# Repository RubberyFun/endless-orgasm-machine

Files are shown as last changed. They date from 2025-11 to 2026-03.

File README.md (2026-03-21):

# Endless Orgasm Machine
**An automated orgasm denial and enhancement device for the DIY community**

### It knows...
What will surprise you most is how accurate it is that you only have a few moments left.  In this day and age algorithms are a respected part of our lives...this one knows you better than yourself.

Have you ever cut-off a sneeze before it happened and found it a conflicting blend of sensations?  Have you ever stopped before your orgasm so you could last a bit longer?  If you're not afraid to use a buttplug and you're ready for an amazing experience this is for you.  

It is not a sex-toy in the traditional sense because it doesn't provide pleasure unless you connect it to other toys.  It is an arousal sensor.  Other devices provide the pleasure, EOM tells them when to stop and when they can start again. (The exception being if you build in an integrated vibrator or e-stim plug)

### The science!
Using an inflatable butt plug to detect pressure changes indicative of pelvic floor contractions, this software, and associated hardware, is used to detect when the user is approaching orgasm and control stimulation accordingly. The net result: automated edging and orgasm denial or enhancement.

### But I like orgasms...

Having to wait for it while being right at the edge makes it more intense!  Trying to resist getting close is a turn-on for some.  When you're ready to end the edging you can use "Control: Orgasm" to allow you to finish after a chosen number of minutes or near-orgasms... if you've had enough simply set it to "Control: Manual" and take control of the toys manually.  It can also be used after orgasms to determine exactly when the refractory period has subsided enough to begin the next round of pleasuring. 

### Bonus feature:
You could use the app by itself to control multiple sex toys at once without am EOM being involved.  The app by itself is a versatile and simple control hub.

## Web UI

[The UI is posted at https://rubberyfun.github.io/endless-orgasm-machine/eomui/public](https://rubberyfun.github.io/endless-orgasm-machine/eomui/public) and can be installed on your Android or PC as a PWA app for offline use. 

This is what the app view looks like:
(the purple icon switches between chart mode and realtime mode)


For legacy purposes the UI is also on the ESP32 itself and can be found by visiting the ```/ui``` endpoint at the IP address of your device.  You can watch the serial output to determine the IP.  Due to space limitations the embedded version can't connect to other toys.  It's basically for monitoring the websocket output.

Example: If you join the EOM WiFi access point the IP will be: ```192.168.4.1``` you should visit ```http://192.168.4.1/ui```  It will automatically open a connection to the websocket endpoint at ```http://192.168.4.1/```.

 

### So how do I get one
Well, I'll get a store together eventually but for now you'll have to build it yourself.  These instructions are meant to make the simplest build possible so you can get playing. 

## Hardware
#### [Build examples here](doc/building/building.md)
STLs for the wrapped tubing version are in the [/hardware](/tree/main/hardware) directory.  

Also included are the source files for customizing your own plug.  They are designed in [OpenSCAD](https://openscad.org/), which may not be the easiest cad program to work with but its completely open-source and easily sharable for customization.

If you go with an inflatable plug you're on your own...There are not yet any files for enclosing the electronics and securing them...there are a million different products you could buy anyways so nothing could be made to fit.  If there is demand I'll post a simple box.

## Building the software
- Install [VSCode](https://code.visualstudio.com/) with the [pioarduino extension](https://github.com/pioarduino/platform-espressif32) (or add https://github.com/pioarduino/platform-espressif32 to the [PlatformIO](https://platformio.org/) extension)
- Open this repo and let all the PlatformIO dependencies download
- If you want to use websockets alongside or instead of bluetooth set "wifi_on" to true and configure your wifi ssid and password at the top of [data/config.json](data/config.json) or skip this step to let it broadcast its own access point: ```EOM```.  You can have it both ways: Set it up to connect to your home wifi but if you're away EOM will go into access point mode after it fails to find it.
- figure out the board you're using.  For a Xiao Seeed Esp32-S3 choose '''esp32-s3-devkitm-1'''.  For Waveshare Esp32-S3 choose ```waveshare_esp32_s3_zero```.  For a generic ESP32 like Wroom choose ```esp32dev```
- Under ```PlatformIO -> Project Tasks -> <your board> -> Platform``` choose ```Build Filesystem Image``` then ```Upload Filesystem Image```
- Under ```PlatformIO -> Project Tasks -> <your board> -> General``` choose ```Build``` then eventually ```Upload and Monitor```
- Watch for your device's IP address to be displayed in the monitor window 
(In access point mode it is 192.168.4.1)



## bluetooth usage
WiFi is NOT necessary anymore!  The UI can work through bluetooth now! No ip address, wifi setup, or anything else needed.  Just connect to your EOM directly by clicking the bluetooth icon.  Android or PC Chrome only! Sorry Apple and Firefox enthusiasts but those two have deemed web bluetooth an unacceptable risk and it will never be available.

So how do you get that running? It is now configured as a PWA!  This means you can pull it up once from https://rubberyfun.github.io/endless-orgasm-machine/eomui/public and install it as an app.  It does not require an internet connection to work after installation...its just there in app mode ready to go.  I'll probably end up splitting the UI into an embedded version and an app version.  

### bluetooth usage with Xtoys:
Using Xtoys you can connect to the EOM and let it control your other Xtoys devices.  For Xtoys it emulates a device called [MonsterPub Mr. Devil Kegel](https://monsterpub.com/products/mp2-u-shaped-remote-egg-with-kegel).  Connect to the device called "Libotoy".  The "pressure" reading corresponds to the "pleasure" output of the EOM.  The sliders for vibrator strength will work in manual mode.

<small>Why Mr Devil?  Because it's one of the few bluetooth devices in Xtoys that has 2 way communication and high resolution (16 bit).  If you wish to connect Xtoys to the EOM over wifi you can choose the Edge-o-matic 3000 and it is backwards compatible.  This is less useful because Xtoys only chose to implement "arousal" and "pressure" inputs, so all the logic that goes into calculating the amount of pleasure is ignored.  </small>

### Pleasure Modes:

|ID|Name|Description|
|---|---|---|
|1|Ramp-Stop|Pleasure ramps up, stopping abruptly on arousal threshold crossing.  It's very frustrating.|
|2|Depletion (default)|Pleasure ramps up, but is reduced for even small arousal spikes.  This makes for a constant interaction with your arousal rather than just a sudden cutoff when it's over the limit|
|3|Enhancement|This is the opposite of edging, it will make you orgasm faster.  Pleasure ramps up as arousal increases, holding a peak for ramp_time.  Not compatible with Orgasm mode.|

## WebSocket API

Websockets are supported for backwards compatibility with nogasm and edge-o-matic devices, but not necessary for the current bluetooth implementation.  Documentation for the WebSocket API can be found in [doc/WebSocket.md](doc/WebSocket.md).

## Building tips

You can test this out on almost any ESP32 device without any extra hardware by touching the pin assigned to the pressure sensor.  Run your finger over all the pins if you're not sure which one it is.  This will be like a pressure sensor being squeezed.  To actually play with this device you will need to attach an actual pressure sensor and butt-plug (or 3d-printed tubing version).  The [MPX5100DP](https://www.digikey.com/en/products/detail/nxp-usa-inc/MPX5100DP/464060) is the sensor it was designed around but anything capable of 15psi or greater should work whether analog or SPI.  Plug the port of the pressure sensor into the air hose for the butt plug.  

To get it to resemble [the original Nogasm device](https://github.com/nogasm/nogasm) you can then add a [12v power supply](https://www.amazon.com/ACEIRMC-Battery-Plastic-Storage-Connect/dp/B0986RMKBJ) and [charger](https://www.amazon.com/Battery-Charger-Lithium-Display-RC123A/dp/B0CRKSFTK9), a [simple transistor](https://www.amazon.com/ALLECIN-IRF4905-Transistors-IRF4905PBF-Transistor/dp/B0CBKGJT9N) or more protected [motor controller](https://www.amazon.com/High-Power-Adjustment-Electronic-Controller-Brightness/dp/B0DZP1NCVW), a [flyback diode](https://www.amazon.com/15SQ045-Diodes-Schottky-Blocking-Silicon/dp/B0D4F2WVS5), and [vibrator motor](https://www.amazon.com/RPTCOTU-R555-Vibration-Motor-Electrodynamic/dp/B0CSYWK5KQ).  You could share that power supply to the esp32 [through a buck converter](https://www.amazon.com/Regulator-Reducer-Converter-Aircraft-MP1584EN/dp/B0B779ZYN1) to make the whole thing wireless.  That's it.  You can set this all up to attach to the buttplug rather than having a wires and tubes leading to a control box, but its a matter of opinion which way is better.  

Tested boards: ESP32DEV, ESP32-WROOM32, ESP32-C6 (WaveShare), ESP32-S3 (Seeed and Waveshare)

### Customization suggestions 
- You can use [Xtoys.app](https://xtoys.app) as a control panel to ramp up any number of vibrators, strokers, or e-stim units in sync with the EOM over bluetooth.  See [this Xtoys layout for an example](https://xtoys.app/layouts/-OcwSDDWBei-Bg4xwe5o)
- If you want to connect Xtoys via wifi you will need to enable SSL in ```data/config.json``` and use the edge-o-matic Xtoys device.  The bluetooth connection is more useful since it sends pleasure level rather than arousal but there are some existing xtoys scripts that work with the edge-o-matic arousal level.
- You can use an inexpensive [Vibrating inflatable buttplug](https://www.amazon.com/Lovehoney-Black-Inflatable-Vibrating-Back/dp/B092VVXM63) and remove its control box to wire it directly to the EOM with a power circuit.  A [non-vibrating plug](https://www.amazon.com/Inflatable-Expandable-Stimulator-Beginners-Detachable/dp/B0DSPKVPM1) is even less expensive if you'll be controlling your pleasure wirelessly.
- If an [MPXV5100GP](https://octopart.com/search?q=MPXV5100GP&currency=USD) pressure sensor is too inconvenient or expensive to source you could use an easy to find [generic car exhaust pressure sensor](https://www.amazon.com/dp/B0997VKYQ9) since they are almost all analog 15psi 5v sensors.  The pin with the notch is Vin, middle is ground, third is Vout. Everything tested was 3V compatible.
- If you use an ESP32 board with an integrated screen ([Example 1](https://www.amazon.com/ideaspark-Development-Integrated-Wireless-Micropython), [Example 2](https://www.amazon.com/Waveshare-Development-Frequency-Single-Core-Processor/dp/B0DHTMYTCY)) you can enable the screen in [include/config.h](include/config.h) to see the IP of the device.
- As an alternative to a vibrating buttplug you can use [a plug made for enema play](https://www.amazon.com/Inflatable-Congestion-Cleaning-Expansion-Beginner/dp/B0CZRLPLQC) and pass a wire through the middle to an e-stim electrode or [to a vibrator on top](https://www.amazon.com/dp/B0024XI1LG).
- Someone posted a build that used tubing wrapped around a 3d printed shaft that also housed the electronics.  It was a neat new twist to the inflatable plug since the tubing reacted to pressure just like an inflatable.  The link is lost to time but it was on github somewhere.
- You could put in a higher range pressure sensor if you prefer to inflate the plug to more intense levels.  The measurement is of change in pressure, not overall pressure.
- You could order a [prebuilt PCB like is used for the Nogasm-esp32](https://github.com/Mathew3000/nogasm-esp32) 
- There really are a ridiculous number of implementations of the nogasm concept from the last decade...you should do some nogasm googling.

## Wait, isn't this the Edge-o-Matic 3000?  Or the Nogasm?

This is a fork of that project with a different set of goals.  The main goal is to make the project accessible to the maker community by keeping the hardware and software simple and DIY friendly - like [the original Nogasm](https://github.com/nogasm/nogasm) that started it all was.  The Edge-o-Matic code is designed around selling well-made but proprietary hardware and is [locked into it through closed-source code](https://github.com/MausTec/eom-hal-dist), crippling attempts to use it with DIY hardware.  It also included a lot of code to connect to related products and services.

This project was first vastly simplified then expanded with compatibility in mind.  You can try it using almost any modern ESP32 device with no additional customization.  You will need to connect a pressure sensor and inflatable buttplug to make it functional, but that's it.  It's meant to be operated wirelessly rather than through the additional hardware of a screen, knob, LEDs, network jack, etc.

Some notable differences are:
- Runs on nearly any ESP32 board!  DIY friendly
- Connects through bluetooth low energy
- Orgasm mode available over UI! (denies orgasms until timer runs out)
- Maximum denial count, so you get to finish after X number of edges
- UI hosted as PWA or on device... and is phone friendly
- defaults to endless orgasm denial in ramp-stop mode
- smaller build size, fits in your butt
- SD card requirement removed
- menu system removed
- console system removed
- action manager system removed
- hardwire networked device support removed 
- edge times are in seconds

## Standing on the shoulders of giants
This is a product of the open source community.  This will always be open source.  Sharing knowledge this way goes back to patent offices, or perhaps cave-man fire.  Sometimes the term can be abused by making things appear open when key information is obfuscated or by taking formerly open repositories offline...that practice of monetizing is also as old as time.  No shame.  Open-source doesn't mean no profiting and I'll try to make some money too. However this particular project intends to focus on information sharing and DIY accessibility as much as functionality.  You should be always be able to build this yourself if you have the free time.  That may not be the most profitable route but I hope the open-source community can elevate this project and make it even more useful than I am capable of.

## Contribution and Inspiration from:

- **Rhobot** with the original [nogasm project](https://github.com/nogasm/nogasm) that started it all
- **TheElims** Gave feedback and works on [a similar device with much more slick hardware](https://github.com/skier233/SmartAssPlug-development) - 
- **Skier23** who curates a [repository](https://github.com/Edging-Machines/Edging-Machines) and [discord](https://discord.gg/EvYbZBf) with all information regarding the topic.
- [Buttplug.io by Qdot](https://buttplug.io/) - Powers the connections from the EOM app to other bluetooth toys.  Him and his discord team are very helpful if irritable.
- **Rudolf**, who came up with the [coiled silicone tube](https://www.thingiverse.com/thing:3543727) as sensor element and even has written a [scientific paper](https://www.degruyter.com/document/doi/10.1515/pjbr-2020-0014/pdf) on that topic.
- **Maus-Tec** who manufactures and sells the [Edge-O-Matic](https://github.com/MausTec/edge-o-matic-3000)
- **Onwrikbaar** with his bullfrog, who refined the simple [nogasm algorithm](https://github.com/Onwrikbaar/Bullfrog) with a peak summation and decay function.
- **night-howler** who contributed a breadboard friendly version of the nogasm called [protogasm](https://github.com/night-howler/protogasm).

### To-do priority
- connect to DG Labs Coyote
- support for more bluetooth LED types
- add build walkthrough to docs and more examples, pinouts and schematics
- audio buzzer in ui for cooldown!
- add a config save button so setting changes aren't immediately permanent (save toy settings also/separately?)
- do canvas drawing to offscreen element for efficiency
- integrate smoothing filters into pressure readings
<!-- - ui and websockets using same endpoint if possible -->
- bug: arousal overflows on hardware side
- logging from the app
- battery monitoring characteristic
- add X axis on chart (seconds)
- chart glitch on left side at startup
- make motor pin selection more intuitive (add motor hardware in general)
- display individual toy battery levels
- bluetooth OTA?
- device disconnection (buttplug bug)
- disable internal motor control option?
- integrated screen support / ip display
- Implement patterns?  That's a biggie
- Running average math seems off

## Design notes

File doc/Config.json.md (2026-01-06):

## Configuration

Please see `data/config.json` file.
If a configuration is changed using the UI it will be saved on the device itself.  There is not currently a way to get the device's config.json back to a computer but most of its contents are transmitted via websocket when the UI first connects.  This is logged by the UI in the browser console.  The file at [/data/config.json](/data/config.json) will overwrite any changes previously saved on the ESP32 when ```PlatformIO -> Project Tasks -> esp32dev -> Platform -> Upload Filesystem Image``` is run.

Here is a quick summary of config variables:

|Key|Type|Default|Note|
|---|----|---|---|
|`wifi_ssid`|String|""|Your WiFi SSID.|
|`wifi_key`|String|""|Your WiFi Password.|
|`wifi_on`|Boolean|false|Enable WiFi and the Websocket server. Cannot be enabled if AzureFang is on.|
|`bt_display_name`|String|"Libotoy"|BT device name.  Currently emulates MonsterPub device for Xtoys compatibility.|
|`bt_on`|Boolean|true|Enable BT connectivity.|
|`force_bt_coex`|Boolean|false|Force BT and WiFi at the same time.|
|`led_brightness`|Byte|128|Status LED maximum brightness.|
|`websocket_port`|Int|80|Port to listen for incoming Websocket connections.|
|`use_ssl`|Boolean|true|Enable SSL server, which is a bit annoying to accept unsigned certificates but required for xtoys compatibility|
|`hostname`|String|"eom3k"|Local hostname for your device.|
|`chart_window_s`|Int|5|The number of seconds to display in the chart history.  Higher numbers can cause sluggish behavior on slower devices|
|`max_denied`|Int|20|Maximum number of denials before forcing an orgasm (in orgasm mode).|
|`initial_pleasure`|Byte|10|The minimum speed the motor will start at in endless & orgasm mode.|
|`max_pleasure`|Byte|255|Maximum speed for the motor in auto-ramp mode.|
|`motor_ramp_time_s`|Int|30|The time it takes for the motor to reach Motor Max Speed in endless & orgasm mode.|
|`edge_delay`|Int|10|Minimum time (s) after edge detection before resuming stimulation.|
|`max_additional_delay`|Int|10|Maximum time (s) that can be added to the edge delay before resuming stimulation. A random number will be picked between 0 and this setting each cycle. 0 to disable.|
|`minimum_on_time`|Int|1|Time (s) after stimulation starts before edge detection is resumed.|
|`pressure_smoothing`|Byte|5|Number of samples to take an average of. Higher results in lag and lower resolution!|
|`classic_serial`|Boolean|false|Output continuous stream of arousal data over serial for backwards compatibility with other software.|
|`sensitivity_threshold`|12 bit Int (4096)|1024|The arousal threshold for orgasm detection. Lower values stop sooner.|
|`mid_threshold`|12 bit Int (4096)|512| The start of the warning zone for approaching arousal.  Changes lights to yellow.|
|`update_frequency_hz`|Int|50|Update frequency for pressure readings and arousal steps. Higher = crash your serial monitor.|
|`sensor_sensitivity`|Byte|128|Pressure sensor prescaling.|
|`use_average_values`|Boolean|false|Use average values when calculating arousal. This smooths noisy data.|
|`vibration_mode`|VibrationMode|RampStop|Vibration Mode for main vibrator control.|
|`use_post_orgasm`|Boolean|false|Use post-orgasm torture mode and functionality.|
|`clench_pressure_sensitivity`|Int|200|Minimum additional Arousal level to detect clench. See manual.|
|`clench_time_to_orgasm_ms`|Int|1500|Threshold variable that is milliseconds count of clench to detect orgasm. See manual.|
|`clench_detector_in_edging`|Boolean|false|Use the clench detector to adjust Arousal. See manual.|
|`auto_edging_duration_minutes`|Int|30|How long to edge before permiting an orgasm.|
|`post_orgasm_duration_seconds`|Int|10|How long to stimulate after orgasm detected.|
|`edge_menu_lock`|Boolean|false|Deny access to menu starting in the edging session.|
|`post_orgasm_menu_lock`|Boolean|false|Deny access to menu starting after orgasm detected.|
|`max_clench_duration_ms`|Int|3000|Duration the clench detector can raise arousal if clench detector turned on in edging session.|
|`clench_time_threshold_ms`|Int|900|Threshold variable that is milliseconds counts to detect the start of clench.|

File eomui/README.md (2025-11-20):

# Endless Orgasm Machine UI

This is a browser-based UI for the Endless Orgasm Machine system for ESP32.



It runs over bluetooth!  Just connect to your EOM directly by clicking the bluetooth icon.  No ip address, wifi setup, or websockets needed.  For now it is Android or PC Chrome or Edge only! Sorry Apple and Firefox enthusiasts but they have deemed web bluetooth an unacceptable risk and it will never be available.  I'm working on a native wrapper to get past this and into the app stores.

It is configured as a PWA!  This means you can pull it up once from https://rubberyfun.github.io/endless-orgasm-machine/eomui/public and install it as an app.  It does not require an internet connection to work after installation...its just there in app-mode ready to go.

It was meant to be stored in spiffs memory on an ESP32 but has outgrown that with the addition of buttplug.io connections to other sex toys.  A simpler version of the built output is included with the larger EOM project for monitoring websocket output. 

It can be run locally if you prefer.  It should be backwards compatible with the Edge-o-Matic & nogasm though missing some features like denial count and Orgasm Mode.


## Use
- Click the bluetooth icon to connect to the EOM (it should be visible as "Libotoy").  The UI will now respond to the pressure applied to the EOM
- Click the duck icon to connect to a toy such as a vibrator.  The toy will now increase in intensity along with the "pleasure" meter of the app.
- If clenches are detected by the EOM the "pleasure" meter will drop accordingly and the toy will follow.

## Building 
- from the eomui directory run ```npm install``` then ```npm run build```
- the output ```index.html``` will automatically overwrite the version in the /data directory of the EOM project.
- using platformIO tools ```build filesystem``` then ```upload filesystem``` to update your device
- the EOM code itself doesn't need to be built/uploaded again

## Development
- run ```vite```
- visit ```http://localhost:5173/``` in your browser
- enter the ip address of your EOM and hit connect - it will open a websocket connection and request a stream of readings
- to speed up development the IP address can be entered into the code on line 8 of [/src/App.svelte](/src/App.svelte) 
- if you need SSL locally use ```npm i @vitejs/plugin-basic-ssl```

## License
This UI was not derived from any previous projects and is released under GPL courtesy of Claus Macher.  If you aren't familiar with GPL it basically means you can do whatever you want with the code but anything you make with it should also be released under GPL.

The buttplug.io library used by this project has a BSD-3 License...which basically means the license and attribution must be distributed with any projects using the code.

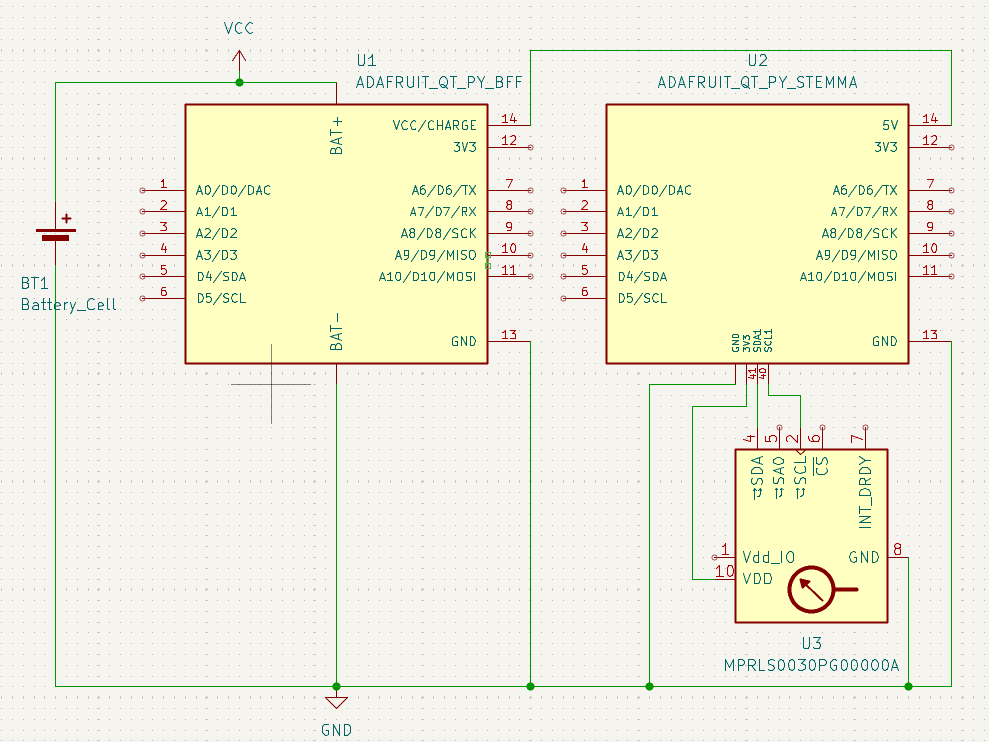
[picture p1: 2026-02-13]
doc/building/QT_PY_wBFF_I2C schematic.png

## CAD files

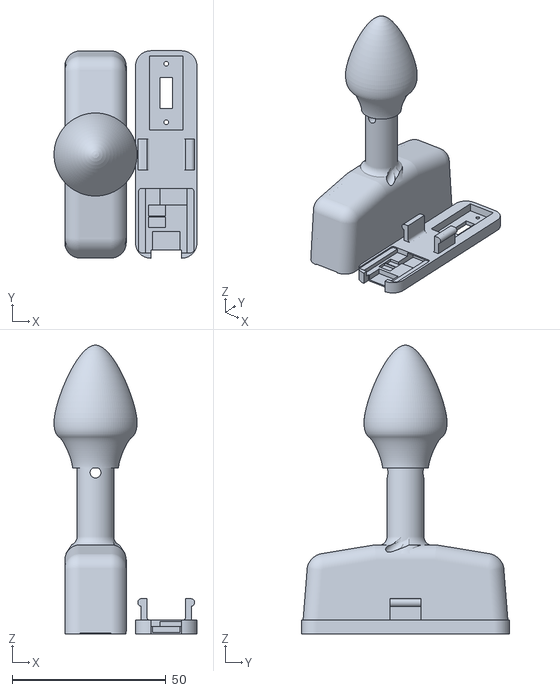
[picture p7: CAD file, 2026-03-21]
hardware/plugXS.stl
46.5 x 67.5 x 94.0

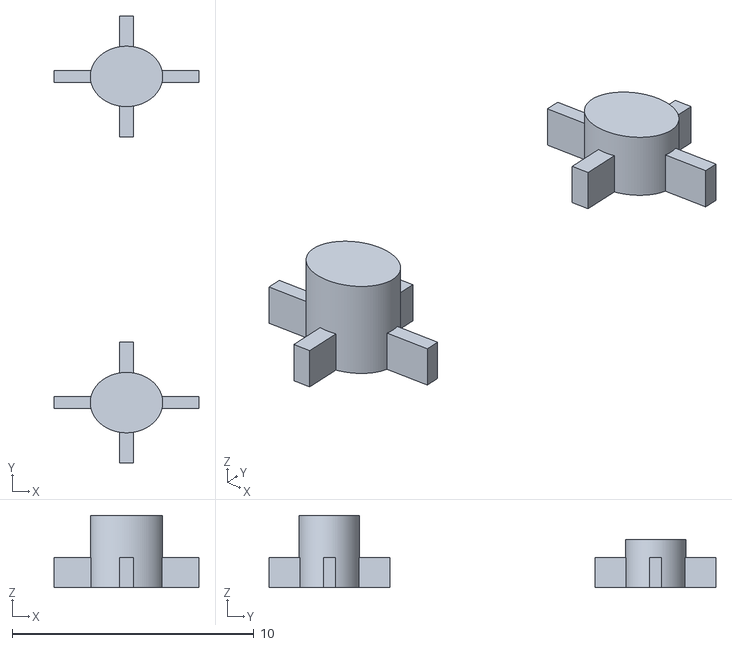
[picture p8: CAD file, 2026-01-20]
hardware/buttons.stl
6.00 x 18.5 x 3.00

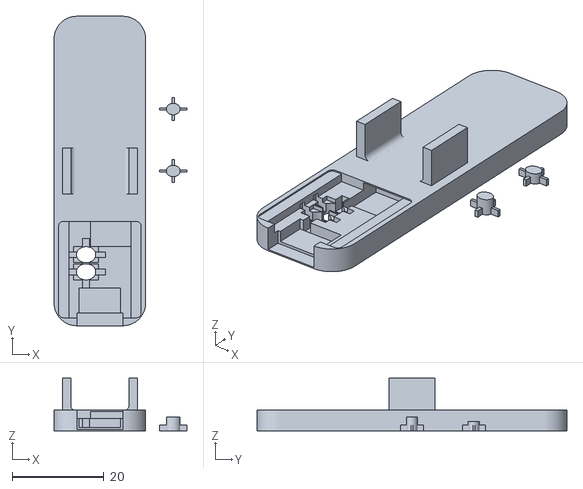
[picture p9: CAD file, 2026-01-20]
hardware/lid.stl
29.0 x 67.5 x 11.5

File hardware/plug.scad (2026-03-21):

include <BOSL2/std.scad> //You will need to install the BOSL2 library to your openSCAD library (https://github.com/BelfrySCAD/BOSL2):
$fn = 100;

show_body = true;
show_lid = true;
lid_offset = true;  //for 3d printing
show_cap = true;
preview_electronics = false; //false for printing
show_mold = false;

seed_w = 18;
seed_h = 2;
seed_l = 21;
usb_d = 9;
usb_w = 9;
usb_h = 3.5;
button_w = 4.5;
button_d = 3.5;
switch_hinge_w = 1;
seed_clearance_h = 1.5;
seed_clearance_w = 13.5;

ps_w = 8;
ps_h = 10;
ps_d = 8;

battery_w = 50;
battery_h = 20;
battery_d = 10;

box_iw = 60;
box_ih = 23;
box_id = 16;
box_top_rise = 3;
box_fillet = 5;
box_bottom_fillet_hack = 5;
box_lid_h = 5.5;
box_lid_side_clip_h = 2;
box_lid_side_clip_l = 7 + box_lid_side_clip_h;
box_lid_side_clip_w = 10;


shaft_od = 12;
shaft_h = 25;

cap_bottom_h = 10;
cap_middle_h = 5;
cap_top_h = 25;
cap_middle_od = 27;

wall_thickness = 2;
tubing_od = 3;
tubing_od_allowance = 1;

switch_screw_l = 19;
switch_screw_d = 1.5;
switch_l = 24;
switch_w = 11;
switch_h = 11;
switch_lever_l = 10;
switch_lever_w = 4;
switch_lever_h = 3;

if (show_lid && !show_mold) 
  if (lid_offset) 
    translate([box_ih, 0, + box_lid_h ]) 
      lid();
  else 
  //translate([box_id/2,0,-box_ih]) 
  lid();
if (show_body && !show_mold) body();
if (show_cap && !show_mold) cap();

box_points = [
  [-box_iw / 2 - wall_thickness * 2, -box_ih / 2 - box_fillet - wall_thickness], //bottom left
  [box_iw / 2 + wall_thickness * 2, -box_ih / 2 - box_fillet - wall_thickness], //bottom right
  //[box_iw/2 + wall_thickness,                     box_ih/2], //top right corner
  for (
    //top right side curve;
    i = bezpath_curve(
      [
        [box_iw / 2 + wall_thickness, box_ih / 2 - box_fillet],
        [box_iw / 2 + wall_thickness, box_ih / 2 - box_fillet / 2],
        [box_iw / 2 + wall_thickness - box_fillet / 2, box_ih / 2],
        [box_iw / 2 + wall_thickness - box_fillet, box_ih / 2 + (box_fillet / (box_iw / 2 + wall_thickness))],
      ]
    )
  ) i,
  [shaft_od / 2 + tubing_od + tubing_od_allowance, box_ih / 2 + box_top_rise], //shaft right
  [-shaft_od / 2 - tubing_od - tubing_od_allowance, box_ih / 2 + box_top_rise], //shaft left
  //[-box_iw/2 - wall_thickness,                    box_ih/2]  //top left corner
  for (
    //top left side curve;
    i = bezpath_curve(
      [
        [-box_iw / 2 - wall_thickness + box_fillet, box_ih / 2 + (box_fillet / (box_iw / 2 + wall_thickness))],
        [-box_iw / 2 - wall_thickness + box_fillet / 2, box_ih / 2],
        [-box_iw / 2 - wall_thickness, box_ih / 2 - box_fillet / 2],
        [-box_iw / 2 - wall_thickness, box_ih / 2 - box_fillet],
      ]
    )
  ) i,
];

bottom_of_shaft = box_ih / 2 + box_top_rise + wall_thickness;

module body() {
  //components compartment
  difference() {
    #union() {
      translate([-box_id / 2 - wall_thickness, 0, tubing_od_allowance * 2])
        rotate([90, 0, 90])
          //filleted top and bottom
          fillet_extrude(height=box_id + wall_thickness * 2, r1=-5, r2=-5)
            polygon(box_points);

      //shaft tubing collar
      difference() {
        translate([0, 0, bottom_of_shaft]) cylinder(h=shaft_od / 2 -.5, d1=box_id + wall_thickness*2 - .825, d2=shaft_od, center=true); //.825 to account for fillet overlap
        translate([0, 0, bottom_of_shaft + 2.75]) torus(id=shaft_od-.001, od=shaft_od * 2, $fn=100);
      }
    }

    //cut off bottom of box
    translate([0, 0, -box_ih / 2 - box_fillet - wall_thickness/2])
      cube([box_iw + wall_thickness * 2, box_iw + wall_thickness * 2 + box_fillet * 2, box_fillet * 2], center=true);

    //insert for esp32
    translate([0,-box_iw/2 + seed_l/2 - wall_thickness, -box_ih/2  -.2501]) qt_py_esp32s3(); //.25 because im getting overhang artifacts when it's flush
    //translate([0, box_iw/2 - seed_l/2 + wall_thickness, -box_ih / 2 +3]) qt_py_bff();

    if (!show_mold) {

      //cavity for electronics
      translate([0, 0, -wall_thickness/2])
        cube([box_id, box_iw, box_ih], center=true);

      //center hole for wire
      cylinder(h=shaft_h + 2, d=tubing_od, center=true); 

      //hole for pressure tube
      translate([shaft_od / 2 + tubing_od / 2, -shaft_od/4, bottom_of_shaft])
        rotate([-45, 0, 0])
          cylinder(h=box_ih, d=tubing_od + tubing_od_allowance / 2, center=true);

      //hole for pressure tube onto shaft
      translate([shaft_od / 2 + tubing_od / 2 + .25,0, bottom_of_shaft+tubing_od/2 + .25]) {

        //this is a failed attempt to use an arc of torus, but i still think its the right approach eventually so it stays
        // rotate([-5,0,0]) translate ([0,1,0]) intersection() {
        //   translate([0,-3,2]) rotate([20,0,0]) rotate([0,90,0]) cylinder(h=30, d=16, center=true,$fn=3);
        //   c = 10;
        //   translate([1,1,-c/1.5 ]) rotate([0,90,-2]) torus(od=c+shaft_od, id=c);     
        // }
       translate([1.1,0,.75]) rotate([110,-15,-8]) cylinder (h=8, d=shaft_od/2, center=true);  //just another cylinder for now

      //tab stays
      for (side = [0,-1]) 
        translate([side *  box_id + .25, 0, - box_ih - wall_thickness]) 
          rotate([90,0,0]) 
            cylinder(h=box_lid_side_clip_w + 4, d=box_lid_side_clip_h + .5, center=true);

      }
        // rotate([-67.5, 0, 0])
        //   cylinder(h=18, d=tubing_od + tubing_od_allowance / 2, center=true);
    }
  }

  if (!show_mold) {
    //shaft
    difference() {
      translate([0, 0, bottom_of_shaft + shaft_h / 2])
        cylinder(h=shaft_h, d=shaft_od, center=true);
      //shaft

      translate([0, 0, bottom_of_shaft + shaft_h / 2])
        cylinder(h=shaft_h + 2, d=tubing_od, center=true);
      //hole up the middle
      translate([0, 0, bottom_of_shaft + shaft_h - tubing_od / 2])
        rotate([90, 0, 0])
          cylinder(h=cap_middle_od + 2, d=tubing_od + tubing_od_allowance / 2, center=true);
      //hole for tubing end
    }
  }
}

top_of_shaft = bottom_of_shaft + shaft_h;

module cap() {
  cap_points = [
    [0, top_of_shaft], //point
    [tubing_od / 4, top_of_shaft],
    [tubing_od / 2, top_of_shaft],
    [shaft_od / 2 + tubing_od / 2, top_of_shaft], //point
    [shaft_od / 2 + tubing_od / 2, top_of_shaft + cap_bottom_h / 4],
    [cap_middle_od / 2 * .75, top_of_shaft + cap_bottom_h - cap_middle_h / 4],
    [cap_middle_od / 2 * .875, top_of_shaft + cap_bottom_h], //point
    [cap_middle_od / 2, top_of_shaft + cap_bottom_h + cap_middle_h / 4],
    [cap_middle_od / 2, top_of_shaft + cap_bottom_h + cap_middle_h * .75],
    [cap_middle_od / 2, top_of_shaft + cap_bottom_h + cap_middle_h], //point
    [cap_middle_od / 2, top_of_shaft + cap_bottom_h + cap_middle_h + cap_top_h / 4],
    [shaft_od / 2, top_of_shaft + cap_bottom_h + cap_middle_h + cap_top_h],
    [0, top_of_shaft + cap_bottom_h + cap_middle_h + cap_top_h], //point
  ];
  rotate_extrude()
    //create cap shape
    polygon(bezpath_curve(cap_points));
}

module lid() {
  //components back cover
  translate([0, 0,-box_ih / 2 - 1]) { // magic -1
    //?
    color("purple") 
      //scale([1, 1, .5])
        difference() {
            cuboid ([box_id + wall_thickness * 2, box_iw + wall_thickness * 3.75, box_lid_h * 2], rounding=box_fillet,edges="Z"); //lid box);

          //cut off top
          translate([0,0, box_lid_h/2]) 
            cube([box_iw + wall_thickness * 2, box_iw + wall_thickness * 2 + box_fillet * 2, box_lid_h +2],center=true);

          //usb cutout
          //translate([0,-box_iw/2 - usb_d + wall_thickness/2,-.5])cube([usb_w + 2, usb_d*2, usb_h + 2], center=true); //magic .5 for height clarance

          //esp32 cutout
          translate([0,-box_iw/2 + seed_l/2 - wall_thickness, -.5]) qt_py_esp32s3(); 
          // translate([0, box_iw/2 - seed_l/2 + wall_thickness, 2.25]) qt_py_bff();  //.25 of cheat
          translate([0, box_iw/2 - switch_l/2 + wall_thickness, switch_lever_h/2]) switch();

          //button press mechanism 
         // #translate([-button_w/2, -box_iw/2 + wall_thickness + button_d/2, -5])
        }

        //bff stays
        // translate([0, box_iw/2 - seed_l/2 + wall_thickness, 1.5]) {
        //   for (side = [-1, 1]) 
        //     color("green") translate([side*6,2.5,-2]) cube([2,4,2], center=true);
        // }

        //side clips
        for (side = [-1, 1]) {
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

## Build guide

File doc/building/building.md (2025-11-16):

# Building an EOM

Todo: build walkthroughs

# Example builds:

### Tiny tubing build with colored lights (~$60)
- $7 [Waveshare ESP32-S3](https://www.amazon.com/dp/B0CR2RH7PS)
- $28 [MPXV5050GP pressure sensor](https://www.digikey.com/en/products/detail/nxp-usa-inc/MPXV5100GP/2186552) + shipping + tax
- $6 [2mm ID silicone tubing](https://www.amazon.com/Rebower-Silicone-Silicon-Brewing-Aquaponics/dp/B0DSPVD4V7)
- $8 [1100ma battery with jst 1.5 connector](https://www.amazon.com/dp/B0F1FN9BY6)
- $6-$11 [USB battery charger](https://www.adafruit.com/product/6091)([amazon source](https://www.amazon.com/Treedix-Protection-Adjustable-Power-Down-Regulation/dp/B09FJJBLQ1) / [amazon source with data passthrough](https://www.amazon.com/Adafruit-4410-Micro-Charger-LiPoly/dp/B08168GWVJ))
- [3d printed base](../../hardware/plugXS.stl)
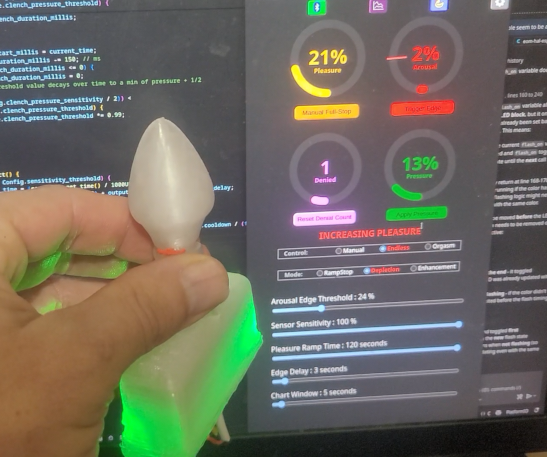
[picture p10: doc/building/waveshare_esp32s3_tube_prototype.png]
Waveshare ESP32-S3 tubing build

---
### Custom PCB (~$150): [Mathew3000/nogasm-esp32](https://github.com/Mathew3000/nogasm-esp32) 
PCB can be ordered online using the files in the repo.  About $150
Mathew3000/nogasm-esp32 

---
### Tiny tubing build with integrated battery (~$60)
- \$8 [Xiao Seeed ESP32-S3](https://www.digikey.com/en/products/detail/seeed-technology-co-ltd/113991114/19285530)  ([$17 on amazon](https://www.amazon.com/ESP32S3-2-4GHz-Dual-core-Supported-Efficiency-Interface/dp/B0BYSB66S5))
- $28 [MPXV5100GP pressure sensor](https://www.digikey.com/en/products/detail/nxp-usa-inc/MPXV5100GP/2186552) \$20 + shipping + tax
- $6 [2mm ID silicone tubing](https://www.amazon.com/Rebower-Silicone-Silicon-Brewing-Aquaponics/dp/B0DSPVD4V7)
- $5 [jst 1.5 connectors](https://www.amazon.com/dp/B07FP2FCYC) 
- $8 [1100ma 102540 battery with jst 1.5 connector](https://www.amazon.com/dp/B0F1FN9BY6)
- [3d printed base](../../hardware/plugXS.stl)

### Small 18650 inflatable build
- $7 [Waveshare ESP32-S3](https://www.amazon.com/dp/B0CR2RH7PS)
- $20 [MPXV5100GP pressure sensor](https://www.digikey.com/en/products/detail/nxp-usa-inc/MPXV5100GP/2186552)
- $15 [inflatable butt plug](https://www.amazon.com/Inflatable-Expandable-Stimulator-Beginners-Detachable/dp/B0DSPKVPM1)
- $20 [battery, charger, and connectors](https://www.amazon.com/dp/B08XZM3NG3)

### Small DIY with all the features (WIP)
- $20 [ESP32-C6 with integrated screen](https://www.amazon.com/dp/B0DHTMYTCY)
- $25 [MPX5100GP pressure sensor](https://www.digikey.com/en/products/detail/nxp-usa-inc/MPX5100GP/464061) (or use the smaller MPXV5100GP if you like)
- $20 [Enema inflatable buttplug](https://www.amazon.com/Inflatable-Congestion-Cleaning-Expansion-Beginner/dp/B0CZRLPLQC)
- An egg electrode (this will connect to your e-stim unit after passing through the plug, not the EOM)
- A small vibrator to fit inside the enema plug
- A transistor to control the vibe with
- A flyback diode to protect the circuit from the motor
- $20 [battery, charger, and connectors](https://www.amazon.com/dp/B08XZM3NG3)
- 3D printed case

### Cheapest possible (~$40 and its usable, but more likely just for testing):
- $15 [inflatable butt plug](https://www.amazon.com/Inflatable-Expandable-Stimulator-Beginners-Detachable/dp/B0DSPKVPM1)
- $12 [generic car exhaust pressure sensor](https://www.amazon.com/dp/B0997VKYQ9)
- $5 [ESP32](https://www.amazon.com/dp/B0F1MS5S8R)
- $7 [18650 cell](https://www.amazon.com/CWUU-9900mAh-Rechargeable-Flashlights-Headlamps/dp/B0D12P7L29)
- $1 [battery holder](https://www.amazon.com/DIANN-10pcs-Battery-Holder-Single/dp/B0BJV7SK5D)
- hot glue and rubber bands, or just use the full length of the tube and let it rest somewhere

Cheapo Build

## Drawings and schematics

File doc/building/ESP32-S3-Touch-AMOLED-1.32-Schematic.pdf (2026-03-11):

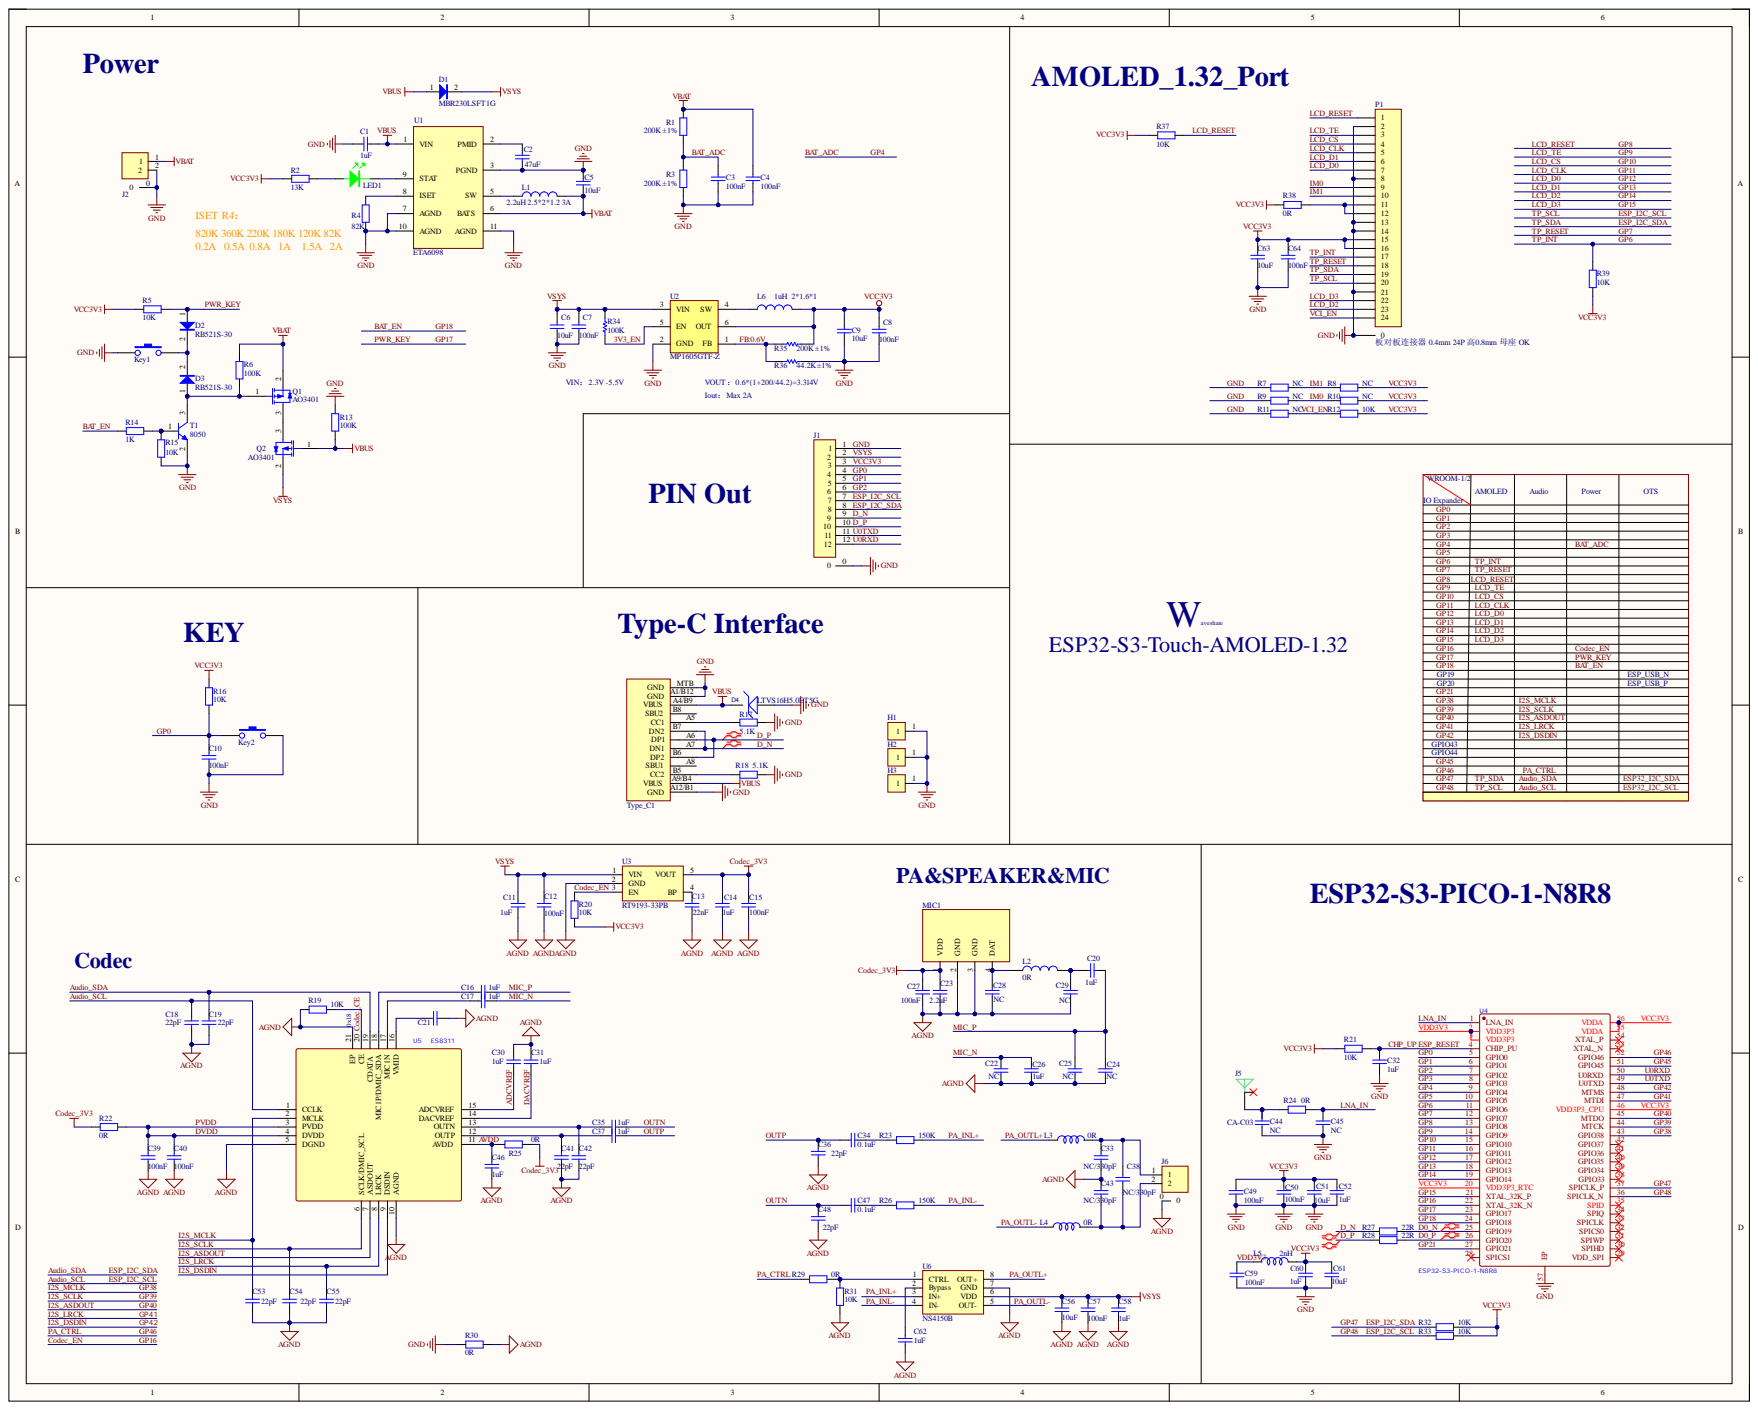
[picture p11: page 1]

GP5
GP6 | TP_INT
GP7 | TP_RESET
GP8 | LCD_RESET
GP9 | LCD_TE
GP10 | LCD_CS
GP11 | LCD_CLK
GP12 | LCD_D0
GP13 | LCD_D1
GP14 | LCD_D2
GP15 | LCD_D3
GP16 | | Codec_EN
GP17 | | PWR_KEY
GP18 | | BAT_EN
GP19 | | | ESP_USB_N

GP47 | TP_SDA | Audio_SDA | ESP32_I2C_SDA
GP48 | TP_SCL | Audio_SCL | ESP32_I2C_SCL

VMID 16 MIC1N 17 MIC1P/DMIC_SDA 18 CDATA 19 CE 20 EP 21

I2S_ASDOUT
I2S_LRCK

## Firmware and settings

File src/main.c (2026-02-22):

#include "api/broadcast.h"
#include "config.h"
#include "config_defs.h"
#include "eom-hal-esp32.h"
#include "freertos/FreeRTOS.h"
#include "freertos/task.h"
#include "gatt_svc.h"
#include "orgasm_control.h"
#include "polyfill.h"
#include "system/http_server.h"
#include "version.h"
#include "wifi_manager.h"
#include <esp_https_ota.h>
#include <esp_ota_ops.h>
#include <esp_system.h>
#include <esp_sleep.h>
#include <driver/gpio.h>
#include "driver/rtc_io.h"
#include <time.h>
#include <nvs_flash.h>
#include <esp_spiffs.h>


char* TAG = "main";


void spiffs_init() {
        ESP_LOGI(TAG, "Initializing SPIFFS");

    esp_vfs_spiffs_conf_t conf = {
      .base_path = "/spiffs",
      .partition_label = "spiffs",
      .max_files = 5,
      .format_if_mount_failed = true
    };

    esp_err_t ret = esp_vfs_spiffs_register(&conf);

    if (ret != ESP_OK) {
        if (ret == ESP_FAIL) {
            ESP_LOGE(TAG, "Failed to mount or format filesystem");
        } else if (ret == ESP_ERR_NOT_FOUND) {
            ESP_LOGE(TAG, "Failed to find SPIFFS partition");
        } else {
            ESP_LOGE(TAG, "Failed to initialize SPIFFS (%s)", esp_err_to_name(ret));
        }
        return;
    }
    ESP_LOGI(TAG, "SPIFFS registered");
}

// static void orgasm_task(void* args) {
    // for (;;) {
    // orgasm_control_tick();

    // vTaskDelay(1);
    // }
// }

static void ble_task(void* args) {
    for (;;) {   
    send_output1();

    vTaskDelay(10);
    }
}


static void loop_task(void* args) {
    // for (;;) {
    static long lastStatusTick = 0;
    static long lastTick = 0;

    // Periodically send out WiFi status:
    if (millis() - lastStatusTick > 1000 * 10) {
        lastStatusTick = millis();
        api_broadcast_network_status();
    }

    if (millis() - lastTick > 1000 / 15) {
        ESP_LOGD(
            TAG,
            "%%heap=%d, min=%d, internal=%d",
            esp_get_free_heap_size(),
            esp_get_minimum_free_heap_size(),
            esp_get_free_internal_heap_size()
        );

        lastTick = millis();
        api_broadcast_readings();
    }

    // Tick and see if we need to save config:
    config_enqueue_save(-1);

    vTaskDelay(1);
}


static void main_task(void* args) {
    orgasm_control_set_output_mode(OC_AUTOMATIC);

    for (;;) {
        //loop_task(NULL);
        orgasm_control_tick();
        eom_hal_led_tick();

        //send_output1();
        vTaskDelay(1);
    }
}

static void sleep_monitor_task(void* args) {
    if (SLEEP_GPIO < 1) {
        ESP_LOGI(TAG, "SLEEP_GPIO not configured, sleep monitor disabled");
        vTaskDelete(NULL);
        return;
    }

    // Configure GPIO as input with pull-down
    gpio_config_t io_conf = {
        .pin_bit_mask = (1ULL << SLEEP_GPIO),
        .mode = GPIO_MODE_INPUT,
        .pull_up_en = GPIO_PULLUP_ENABLE,
        .pull_down_en = GPIO_PULLDOWN_DISABLE,
        .intr_type = GPIO_INTR_DISABLE
    };
    esp_err_t ret = gpio_config(&io_conf);
    if (ret != ESP_OK) {
        ESP_LOGE(TAG, "Failed to configure SLEEP_GPIO %d: %s", SLEEP_GPIO, esp_err_to_name(ret));
        vTaskDelete(NULL);
        return;
    }

    ESP_LOGI(TAG, "Sleep monitor initialized on GPIO %d", SLEEP_GPIO);

    TickType_t sleep_debounce_until = 0;

    for (;;) {
        int level = gpio_get_level(SLEEP_GPIO);
        ESP_LOGD(TAG, "Sleep signal on GPIO %d", level);
        
        // Ignore LOW levels during debounce period
        if (level == 0 && xTaskGetTickCount() < sleep_debounce_until) {
            ESP_LOGD(TAG, "Ignoring LOW level during debounce period");
            vTaskDelay(pdMS_TO_TICKS(100));
            continue;
        }
        
        if (level == 0) {
            ESP_LOGI(TAG, "Entering sleep...");
            
            
            // Configure wake-up source
            
            if (LED_POWER > -1) {
                gpio_set_level(LED_POWER, 0); //power off the LED
            }
            
            // Disable pullup for sleep
            // io_conf.pull_up_en = GPIO_PULLUP_DISABLE;
            // esp_err_t ret = gpio_config(&io_conf);
            if (ret != ESP_OK) {
                ESP_LOGE(TAG, "Failed to re-configure SLEEP_GPIO %d: %s", SLEEP_GPIO, esp_err_to_name(ret));
            }
            
            // Give time for log message to be sent and button to be released
            
            // Enter sleep
            // rtc_gpio_pullup_dis(SLEEP_GPIO);
            // rtc_gpio_pulldown_en(SLEEP_GPIO);
            // esp_sleep_enable_ext0_wakeup(SLEEP_GPIO, 1);
            vTaskDelay(pdMS_TO_TICKS(500));
            esp_sleep_enable_gpio_wakeup();
            gpio_wakeup_enable(SLEEP_GPIO, GPIO_INTR_LOW_LEVEL);
            esp_light_sleep_start();
            ESP_LOGI(TAG, "esp_sleep.wake_reason=%d", esp_sleep_get_wakeup_cause());
            
            // Set debounce period: ignore LOW levels for 1 second after waking
            sleep_debounce_until = xTaskGetTickCount() + pdMS_TO_TICKS(1000);
            
            // rtc_gpio_deinit(SLEEP_GPIO) ;
            // Re-enable pullup for sleep
            // io_conf.pull_up_en = GPIO_PULLUP_ENABLE;
            ret = gpio_config(&io_conf);
            if (ret != ESP_OK) {
                ESP_LOGE(TAG, "Failed to re-configure SLEEP_GPIO %d: %s", SLEEP_GPIO, esp_err_to_name(ret));
            }

            if (LED_POWER > -1) {
                gpio_set_level(LED_POWER, 1); //power on the LED
            }
        }
        
        // Check every 100ms - this MUST be here to prevent watchdog
        vTaskDelay(pdMS_TO_TICKS(100));
    }
}

esp_err_t run_boot_diagnostic(void) {
    esp_err_t err = ESP_ERR_INVALID_ARG;
    esp_ota_img_states_t ota_state = ESP_OTA_IMG_UNDEFINED;

    const esp_partition_t* configured = esp_ota_get_boot_partition();
    const esp_partition_t* running = esp_ota_get_running_partition();

    if (configured != running) {
        ESP_LOGW(
            TAG,
            "Configured OTA boot partition at offset 0x%08" PRIx32
            ", but running from offset 0x%08" PRIx32,
            configured->address,
            running->address
        );
        ESP_LOGW(
            TAG,
            "(This can happen if either the OTA boot data or preferred boot image become corrupted "
            "somehow.)"
        );
    }

    ESP_LOGD(
        TAG,
        "Running partition type %d subtype %d (offset 0x%08" PRIx32 ")",
        running->type,
        running->subtype,
        running->address
    );

    if (esp_ota_get_state_partition(running, &ota_state) == ESP_OK) {
        if (ota_state == ESP_OTA_IMG_PENDING_VERIFY) {
            // if (diagnostic_is_ok) {
            ESP_LOGI(TAG, "Diagnostics completed successfully! Continuing execution ...");
            esp_ota_mark_app_valid_cancel_rollback();
            err = ESP_OK;
            // } else {
            // ESP_LOGE(TAG, "Diagnostics failed! Start rollback to the previous version ...");
            // esp_ota_mark_app_invalid_rollback_and_reboot();
            // }
        }
    }

    return err;
}

void app_main() {
    //esp_log_level_set(TAG, ESP_LOG_DEBUG);
    TickType_t boot_tick = xTaskGetTickCount();

    esp_err_t ret = nvs_flash_init();
    if (ret == ESP_ERR_NVS_NO_FREE_PAGES || ret == ESP_ERR_NVS_NEW_VERSION_FOUND) {
        ESP_ERROR_CHECK(nvs_flash_erase());
        ret = nvs_flash_init();
    }
    ESP_ERROR_CHECK(ret);

    spiffs_init();
    ESP_LOGI(TAG, "SPIFFS initialization returned.");
    config_init();
    ESP_LOGI(TAG, "Config initialization returned.");
    eom_hal_led_init();
    ESP_LOGI(TAG, "LED initialization returned.");
    orgasm_control_init();
    ESP_LOGI(TAG, "Orgasm control initialization returned.");

    if (MOTOR1_ENABLED || MOTOR2_ENABLED) {
        eom_hal_init_motor();
        ESP_LOGI(TAG, "Motor initialization returned.");
    }


    printf("Claus Macher presents the Endless Orgasm Machine\n");
    printf("Version: %s\n", EOM_VERSION);

    //Post-Update Diagnostics
    esp_err_t dxerr = run_boot_diagnostic();
    if (dxerr != ESP_ERR_INVALID_ARG) {
        if (dxerr == ESP_OK) {
            ESP_LOGI(TAG, "%s\n%s", "Update complete.", EOM_VERSION);
        }
    }

    // Green = prepare Networking
    // vTaskDelayUntil(&boot_tick, 1000UL / portTICK_PERIOD_MS);
    //eom_hal_set_encoder_rgb(0, 255, 0);


    // Initialize Bluetooth
    // Blue = prepare Bluetooth and Drivers
    // vTaskDelayUntil(&boot_tick, 1000UL / portTICK_PERIOD_MS);
    //eom_hal_set_encoder_rgb(0, 0, 255);

    if (Config.bt_on) {
        ble_host_config_init();
        ESP_LOGI(TAG, "Bluetooth initialization returned.");
    }


    // Initialize WiFi
    if (Config.wifi_on) {
        http_server_init();
        ESP_LOGI(TAG, "HTTP Server initialization returned.");
        wifi_manager_init();
        ESP_LOGI(TAG, "WiFi Manager initialization returned.");
        ESP_LOGI(TAG, "IP Address: %s", wifi_manager_get_local_ip());
    }


    ESP_LOGI(TAG, "System initialization complete.");
    xTaskCreate(main_task, "MAIN", 1024 * 12, NULL, tskIDLE_PRIORITY + 1, NULL);
    xTaskCreate(ble_task, "BT", 1024 * 12, NULL, tskIDLE_PRIORITY + 2, NULL);
    xTaskCreate(sleep_monitor_task, "SLEEP", 1024 * 4, NULL, tskIDLE_PRIORITY, NULL);
    ESP_LOGI(TAG, "Tasks created, entering main loop.");
}   

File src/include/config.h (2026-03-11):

#ifndef __config_h
#define __config_h

#ifdef __cplusplus
extern "C" {
#endif

#include <stdbool.h>
#include <stddef.h>
#include <stdint.h>
#include "led_strip.h"

#define MOTOR1_ENABLED 1
#define MOTOR2_ENABLED 1

// SD card files:
#define CONFIG_PATH_MAX 64

// This is just a default, others can be loaded after boot.
static const char* CONFIG_FILENAME = "/spiffs/config.json";

// String Lengths
#define WIFI_SSID_MAX_LEN 64
#define WIFI_KEY_MAX_LEN 64

#define GATTS_SERVICE_EOM_UUID     0x6969
#define GATTS_CHAR_STATUS_UUID     0x696A
#define GATTS_CHAR_UPDATE_UUID     0x696B
#define GATTS_CHAR_CONFIG_UUID     0x696C

#define GATTS_SERVICE1_UUID        0x6000
#define GATTS_OUTPUT1_CHAR_UUID    0x6031
#define GATTS_OUTPUT2_CHAR_UUID    0x1903
#define GATTS_INPUT1_CHAR_UUID     0x6003
#define GATTS_INPUT2_CHAR_UUID     0x6004


enum pressure_sensor_type {
    PRESSURE_SENSOR_ANALOG,
    PRESSURE_SENSOR_SPI,
    PRESSURE_SENSOR_I2C
};

enum pressure_sensor_hardware {
    PRESSURE_SENSOR_HARDWARE_ANALOG,
    PRESSURE_SENSOR_HARDWARE_MPR,
    PRESSURE_SENSOR_HARDWARE_HX711  //maybe later, MPR is preferred
};

typedef enum pressure_sensor_type pressure_sensor_type_t;
typedef enum pressure_sensor_hardware pressure_sensor_hardware_t;

#ifndef LED_POWER
    #define LED_POWER -1
#endif

#ifndef SLEEP_GPIO
    #define SLEEP_GPIO -1
#endif

#ifdef LED_FORMAT
    #if LED_FORMAT == 1
        #define LED_STRIP_COLOR_COMPONENT_FMT LED_STRIP_COLOR_COMPONENT_FMT_RGB
    #elif LED_FORMAT == 2
        #define LED_STRIP_COLOR_COMPONENT_FMT LED_STRIP_COLOR_COMPONENT_FMT_GRB
    #endif
#else
    #define LED_STRIP_COLOR_COMPONENT_FMT LED_STRIP_COLOR_COMPONENT_FMT_GRB // Default
#endif

#define MINIMUM_BLINK_L 40

#ifndef PRESSURE_SENSOR
    #define PRESSURE_SENSOR PRESSURE_SENSOR_ANALOG
#endif

#ifndef PRESSURE_SENSOR_HARDWARE
    #define PRESSURE_SENSOR_HARDWARE PRESSURE_SENSOR_HARDWARE_MPR
#endif

//which pin to read analog pressure sensor from
//This can accept any ADC_UNIT_1 channel...so ADC_CHANNEL_0 to ADC_CHANNEL_7
#ifndef PRESSURE_GPIO
    #define PRESSURE_GPIO ADC_CHANNEL_0
#endif

#ifndef ADC_UNIT
    #define ADC_UNIT ADC_UNIT_1
#endif

#ifndef PRESSURE_SCL 
    #define PRESSURE_SCL -1 //shared by SPI and I2C SCK configs
#endif

#ifndef PRESSURE_SDA
    #define PRESSURE_SDA -1 //for I2C
#endif

//ADC_CHANNEL_0 is gpio 5 on Xaio Seed ESP32-S3, labeled D5 (LED pin is D21) 
//ADC_CHANNEL_0 is gpio 1 on Waveshare ESP32-S3, labeled 1  (LED pin is 21, ws2812)
//ADC_CHANNEL_0 is gpio 36 on NodeMCU ESP32S, labeled SVP. (another channel might be more accurate)  (LED pin is 2)
//ADC_CHANNEL_0 is gpio 36 on Wroom32, labeled VP  (LED pin is 2)
//ADC_CHANNEL_0 is gpio 0 on Waveshare ESP32-C6-LCD-1.47 labeled 0 (LED pin is 8)

//#define LED_GPIO 2 // This is handled per board in platformio.ini now

#define EOM_HAL_PRESSURE_MAX 0x0FFF // 12 bits ADC reading is standard for esp32

#define DEFAULT_AMBIENT_PRESSURE 0
#define PRESSURE_MULTIPLIER 10   // Scales raw pressure reading for I2C sensors

extern bool isConnected;

enum command_err {
    CMD_FAIL = -1,
    CMD_OK = 0,
    CMD_ARG_ERR = 1,
    CMD_SUBCOMMAND_NOT_FOUND = 253,
    CMD_SUBCOMMAND_REQUIRED = 254,
    CMD_NOT_FOUND = 255,
};

typedef enum command_err command_err_t;

//typedef command_err_t (*command_func_t)(int argc, char** argv, console_t* console);

// Vibration Modes
// See vibration_mode_controller.h for more.

enum vibration_mode { RampStop = 1, Depletion = 2, Enhancement = 3, Pattern = 4, GlobalSync = 0 };

typedef enum vibration_mode vibration_mode_t;

/**
 * Main Configuration Struct!
 *
 * Place all presistent runtime config variables in here, and be sure to add the appropriate def
 * in config.c!
 */

// Increment this if you need to trigger a migration on the system config file.
// Your migration should be defined in config_migrations.c
#define SYSTEM_CONFIG_FILE_VERSION 3
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

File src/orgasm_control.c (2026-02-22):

#include "orgasm_control.h"
#include "config.h"
#include "eom-hal-esp32.h"
#include "esp_log.h"
#include "esp_timer.h"
#include "util/running_average.h"
#include <math.h>
#include <stdio.h>
#include <string.h>
#include <time.h>

static const char* TAG = "orgasm_control";

static const char* orgasm_output_mode_str[] = {
    "MANUAL",
    "ENDLESS",
    "ORGASM",
};

static struct {
    unsigned long last_update_ms;
    running_average_t* average;
    uint16_t last_value;
    uint16_t pressure_value;
    uint16_t peak_start;
    uint16_t arousal;
    uint8_t update_flag;
    unsigned long cooldown;
} arousal_state;

static struct {
    orgasm_output_mode_t output_mode;
    vibration_mode_t vibration_mode;
    unsigned long motor_stop_time;
    unsigned long motor_start_time;
    unsigned long edge_time_out; // 10000?
    unsigned long random_additional_delay;
    int twitch_count;
    uint8_t control_motor;
    uint8_t prev_control_motor;
    float pleasure;
} output_state;

static struct {
    // File Writer
    unsigned long recording_start_ms;
    FILE* logfile;
} logger_state;

static struct {
    //  Post Orgasm Clench variables
    long clench_pressure_threshold; //  4096?
    int clench_duration;

    // Autoedging Time and Post-Orgasm varables
    unsigned long auto_edging_start_millis;
    unsigned long post_orgasm_start_millis;
    unsigned long post_orgasm_duration_millis;
    unsigned long clench_start_millis;
    long clench_duration_millis;
    oc_bool_t menu_is_locked;
    oc_bool_t detected_orgasm;
    int post_orgasm_duration_seconds;
} post_orgasm_state;

volatile static struct {
    uint8_t orgasm_count;
    //event_handler_node_t* _h_orgasm;
} orgasm_state = { 0 };

// static void _evt_orgasm_start(
//     const char* evt, EVENT_HANDLER_ARG_TYPE eap, int eai, EVENT_HANDLER_ARG_TYPE hap
// ) {
//     if ( orgasm_control_is_permit_orgasm_reached() ) {
//         post_orgasm_state.detected_orgasm = ocTRUE;
//     }
//     //orgasm_state.orgasm_count += 1;
// }

#define update_check(variable, value)                                                              \
    {                                                                                              \
        if (variable != (value)) {                                                                 \
            ESP_LOGD(TAG, "updated: %s = %s", #variable, #value);                                  \
            variable = value;                                                                      \
            arousal_state.update_flag = ocTRUE;                                                    \
        }                                                                                          \
    }
uint8_t orgasm_control_get_orgasm_count(void) {
    return orgasm_state.orgasm_count;
}
uint8_t orgasm_control_get_arousal_sensitivity(void) {
    return Config.sensor_sensitivity;
}


/**
 * @brief Simplified method to set pleasure, which also handles broadcasting the event.
 * @param pleasure pleasure value
 * @param use_motor Whether to actually control the motor hardware (defaults to true)
 */
void orgasm_control_set_pleasure_ex(uint8_t pleasure, bool use_motor) {
    if (pleasure > Config.max_pleasure) pleasure = Config.max_pleasure;

    if (use_motor) {
        #if MOTOR1_ENABLED
        eom_hal_set_motor1_speed((uint8_t) pleasure);
        #endif
        #if MOTOR2_ENABLED
        eom_hal_set_motor2_speed((uint8_t) pleasure);
        #endif
    }

    //output_state.pleasure = pleasure;
}

/**
 * @brief Convenience wrapper that calls orgasm_control_set_pleasure_ex with control_motor=true
 * @param pleasure pleasure value
 */
void orgasm_control_set_pleasure(uint8_t pleasure) {
    orgasm_control_set_pleasure_ex(pleasure, true);
}

void orgasm_control_init(void) {
    eom_hal_init_pressure_sensor();
    ESP_LOGI(TAG, "Pressure sensor initialized.");
    output_state.output_mode = OC_AUTOMATIC;
    output_state.vibration_mode = Config.vibration_mode;
    output_state.edge_time_out = 10000;
    post_orgasm_state.clench_pressure_threshold = 4096;    
    arousal_state.cooldown = 0; 

    running_average_init(&arousal_state.average, Config.pressure_smoothing);
    ESP_LOGI(TAG, "Running average initialized with window size %d.", Config.pressure_smoothing);
    orgasm_state.orgasm_count = 0;  
    // if (orgasm_state._h_orgasm == NULL) {
    //     orgasm_state._h_orgasm =
    //         event_manager_register_handler(EVT_ORGASM_START, &_evt_orgasm_start, NULL);
    // }
}

static const vibration_mode_controller_t* get_vibration_mode_controller() {
    switch (Config.vibration_mode) {
    case Enhancement: return &EnhancementController;

    default:
    case Depletion: return &DepletionController;

    case Pattern: return &PatternController;

    case RampStop: return &RampStopController;
    }
}
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

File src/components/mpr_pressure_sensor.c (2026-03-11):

#include "components/mpr_pressure_sensor.h"
#include "driver/i2c_master.h"
#include "freertos/FreeRTOS.h"
#include "esp_log.h"

static const char* TAG = "MPR_SENSOR";
const uint8_t MPR_PRESSURE_REQ[3] = {0xAA, 0x00, 0x00};

void mpr_dev_config(i2c_device_config_t* config) {
    config->dev_addr_length = I2C_ADDR_BIT_LEN_7;
    config->device_address = MPR_I2C_ADDRESS;
    config->scl_speed_hz = 100000;  // 100kHz - 400kHz supported
}

esp_err_t mpr_read_pressure(i2c_master_dev_handle_t dev_handle, int32_t* pressure) {
    uint8_t data[MPR_PRESSURE_RESPONSE_LEN];
    esp_err_t ret = ESP_FAIL;
    uint8_t status = 0;
    int retries = MPR_READ_RETRIES;


    while (retries--) {
        // Send pressure request command
        ESP_LOGD(TAG, "Sending pressure request (attempt %d/%d)...", MPR_READ_RETRIES - retries, MPR_READ_RETRIES);
        
        // Use a reasonable timeout for the I2C transaction itself (not sensor processing time)
        ret = i2c_master_transmit(dev_handle, (const uint8_t*)MPR_PRESSURE_REQ, sizeof(MPR_PRESSURE_REQ), MPR_TIMEOUT_MS);
        
        if (ret != ESP_OK) {
            ESP_LOGD(TAG, "Transmit failed: %s (0x%x)", esp_err_to_name(ret), ret);
            
            // If invalid state, the bus might be stuck - try to continue anyway
            if (ret == ESP_ERR_INVALID_STATE) {
                ESP_LOGD(TAG, "I2C bus in invalid state, attempting to continue...");
                vTaskDelay(pdMS_TO_TICKS(MPR_READ_WAIT_MS)); // Give bus time to recover
                continue;
            }
            return ret;
        }

        ESP_LOGD(TAG, "Request sent successfully, waiting for sensor to process...");

        vTaskDelay(MPR_READ_WAIT_MS / portTICK_PERIOD_MS);  // Wait for sensor to process and get response
        ret = i2c_master_receive(dev_handle, data, MPR_PRESSURE_RESPONSE_LEN, MPR_TIMEOUT_MS);

        // ret = i2c_master_transmit_receive(dev_handle, (const uint8_t*)MPR_PRESSURE_REQ, sizeof(MPR_PRESSURE_REQ), data, MPR_PRESSURE_RESPONSE_LEN, MPR_TIMEOUT_MS); // Transmit request and receive response in one transaction
        ESP_LOGD(TAG, "Response received, parsing...");

        if (ret == ESP_OK) {
            status = data[0];
            ESP_LOGD(TAG, "Status byte: 0x%02X", status);

            // Check for error conditions
            if (!(status & MPR_STATUS_MASK_POWER_ON)) {
                ESP_LOGD(TAG, "Sensor not powered on");
                return ESP_ERR_INVALID_STATE;
            }
            if (status & MPR_STATUS_MASK_INTEGRITY_TEST_FAILED) {
                ESP_LOGD(TAG, "Sensor integrity test failed");
                return ESP_ERR_INVALID_RESPONSE;
            }
            if (status & MPR_STATUS_MASK_MATH_SATURATION) {
                ESP_LOGD(TAG, "Sensor math saturation error");
                return ESP_ERR_INVALID_RESPONSE;
            }

            // Check if sensor is still busy
            if (status & MPR_STATUS_MASK_BUSY) {
                ESP_LOGD(TAG, "Sensor still busy, retrying...");
                vTaskDelay(MPR_READ_WAIT_MS / portTICK_PERIOD_MS);
                continue;  // Retry the read
            }
            
            // Successful read - sensor is ready and has data
            ESP_LOGD(TAG, "Pressure data: 0x%02X 0x%02X 0x%02X", data[1], data[2], data[3]);
            *pressure = ((int32_t)data[1] << 16) | ((int32_t)data[2] << 8) | (int32_t)data[3];
            return ESP_OK;
        } else {
            ESP_LOGD(TAG, "Receive failed: %s (0x%x)", esp_err_to_name(ret), ret);
        }
    }

    if (ret == ESP_OK && status != 0) {
        return (esp_err_t)status;  //might help debugging
    } else {
        return ESP_FAIL;
    }
}

esp_err_t mpr_scan_i2c_bus(i2c_master_bus_handle_t bus_handle) {
    ESP_LOGI(TAG, "Scanning I2C bus...");
    uint8_t found_devices = 0;
    
    for (uint8_t addr = 0x03; addr < 0x78; addr++) {
        // Create temporary device config for this address
        i2c_device_config_t probe_cfg = {
            .dev_addr_length = I2C_ADDR_BIT_LEN_7,
            .device_address = addr,
            .scl_speed_hz = 100000,
        };
        
        i2c_master_dev_handle_t probe_handle;
        esp_err_t ret = i2c_master_bus_add_device(bus_handle, &probe_cfg, &probe_handle);
        
        if (ret == ESP_OK) {
            // Try to probe the device
            ret = i2c_master_probe(bus_handle, addr, 100);
            
            if (ret == ESP_OK) {
                ESP_LOGI(TAG, "Found device at address 0x%02X", addr);
                found_devices++;
                
                if (addr == MPR_I2C_ADDRESS) {
                    ESP_LOGI(TAG, "  ^--- This is the expected MPR sensor address!");
                }
            }
            
            i2c_master_bus_rm_device(probe_handle);
        }
    }
    
    if (found_devices == 0) {
        ESP_LOGW(TAG, "No I2C devices found! Check wiring and power.");
        return ESP_ERR_NOT_FOUND;
    } else {
        ESP_LOGI(TAG, "I2C scan complete. Found %d device(s).", found_devices);
        return ESP_OK;
    }
}

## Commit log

2025-11-16 mono led support for arousal state
2025-11-23 lets break out the individual controls of a device
2025-12-03 LED WIP Govee
2026-01-07 pressure cleanup, sleep start, sync bs, controller tweaks
2026-01-20 more modeling
    [buttons.stl, lid.stl, plug.scad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]
2026-02-13 schematics and possum update
    [Schematic_esp32_analog.kicad_sch, Schematic_esp32_analog_charger.kicad_sch, Schematic_qt_py_analog.kicad_sch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]
2026-03-11 making seeed esp32s3 default setup. simplifying config
2026-03-21 kiss my app
    [plug.scad, plugXS.stl]
